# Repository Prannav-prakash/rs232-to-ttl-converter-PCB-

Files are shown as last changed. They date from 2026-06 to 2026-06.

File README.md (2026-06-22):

# RS232-to-ttl-converter-PCB
RS232 to TTL interface PCB for connecting an Inertial Labs INS-DU to a Cube Orange Plus flight controller at 921600 bps.

# Overview

This project implements a dedicated RS232-to-TTL interface board for communication between an Inertial Labs INS-DU navigation system and a Cube Orange Plus flight controller.

The board performs RS232 level shifting using the MAX3232E transceiver while also providing a power passthrough interface from an external BEC to the INS-DU. The design supports high-speed serial communication at up to 921600 baud and was developed using KiCad.

# Features
RS232 to TTL voltage level conversion using MAX3232
Compatible with Cube Orange Plus flight controller
Compatible with Inertial Labs INS-DU navigation system
Supports serial communication up to 921600 baud
External BEC power passthrough to INS-DU

# System Architecture

Cube Orange Plus UART (TTL)

↓

MAX3232E Level Shifter

↓

INS-DU RS232 Interface

Power for the INS-DU is supplied independently through an external BEC and routed through the PCB.

# Hardware Components
Integrated Circuits
MAX3232E RS232 Transceiver
Passive Components
Charge pump capacitors required by MAX3232
Power supply decoupling capacitor
Connectors
Cube Orange Plus Interface Connector
INS-DU Interface Connector
BEC Power Input Connector

# Repository Contents
KiCad Schematic Files

KiCad PCB Layout Files

Custom Symbols

Custom Footprints

3D Models

Documentation

Images
# PCB layout


# schematic 


# 3D view 


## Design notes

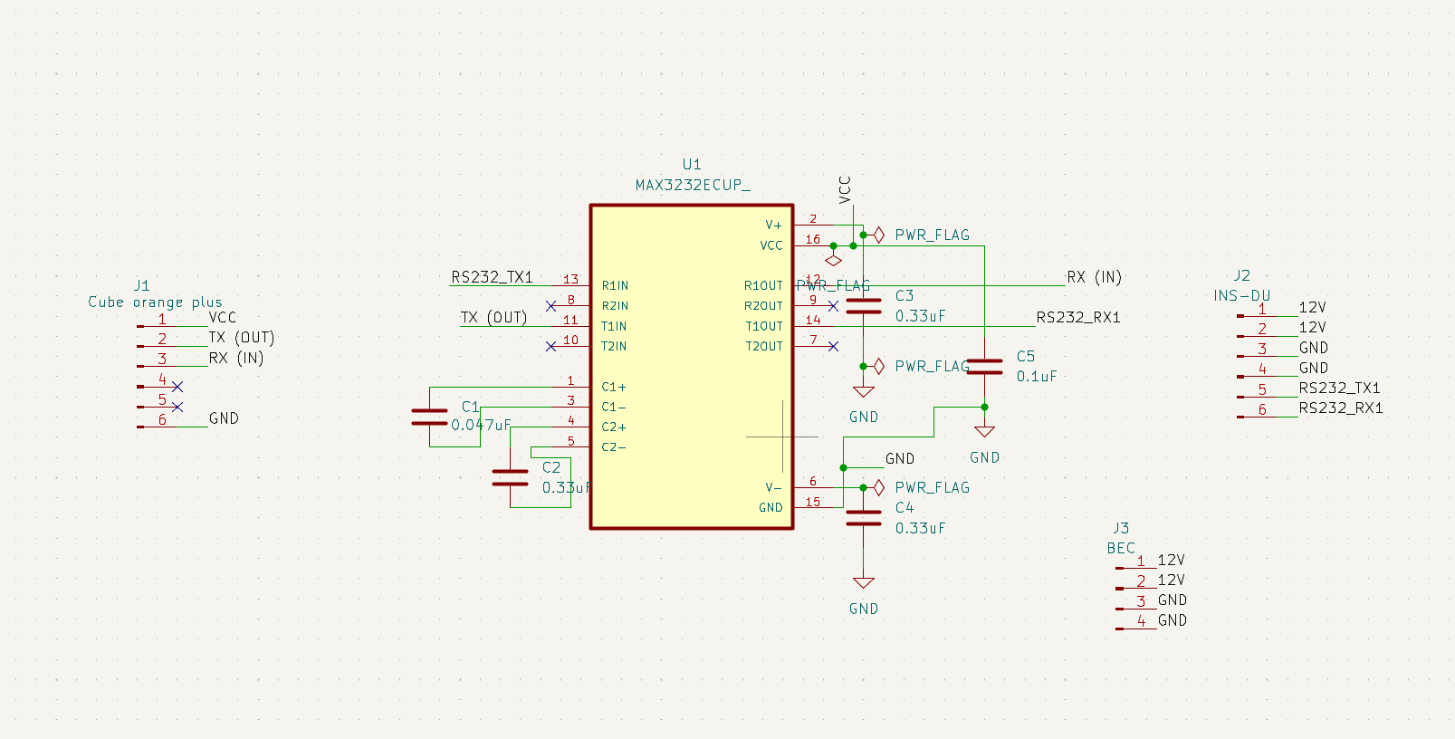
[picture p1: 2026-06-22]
schematic.png

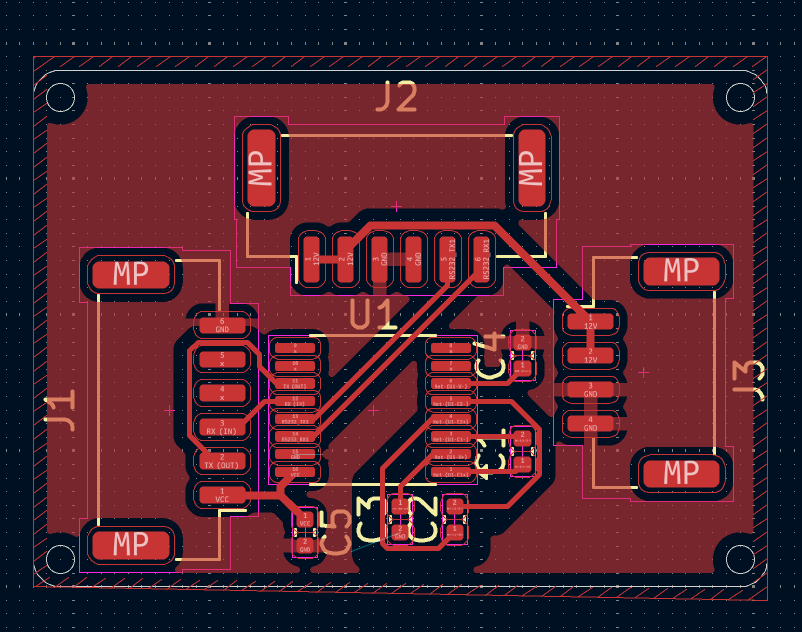
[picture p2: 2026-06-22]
PCB.png

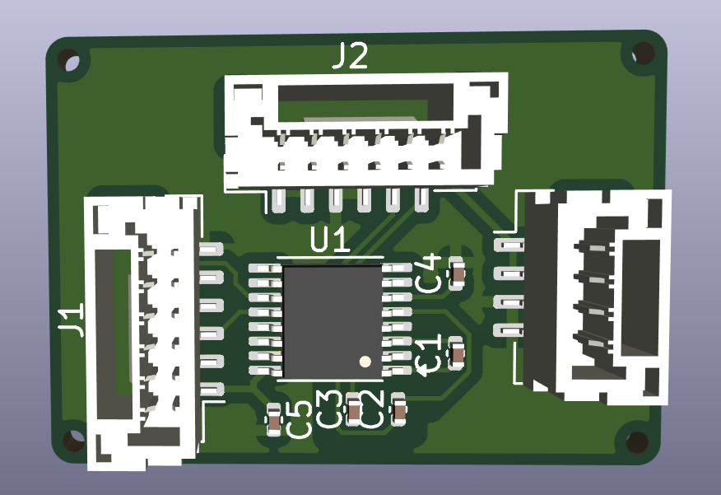
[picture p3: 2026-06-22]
3D view.png

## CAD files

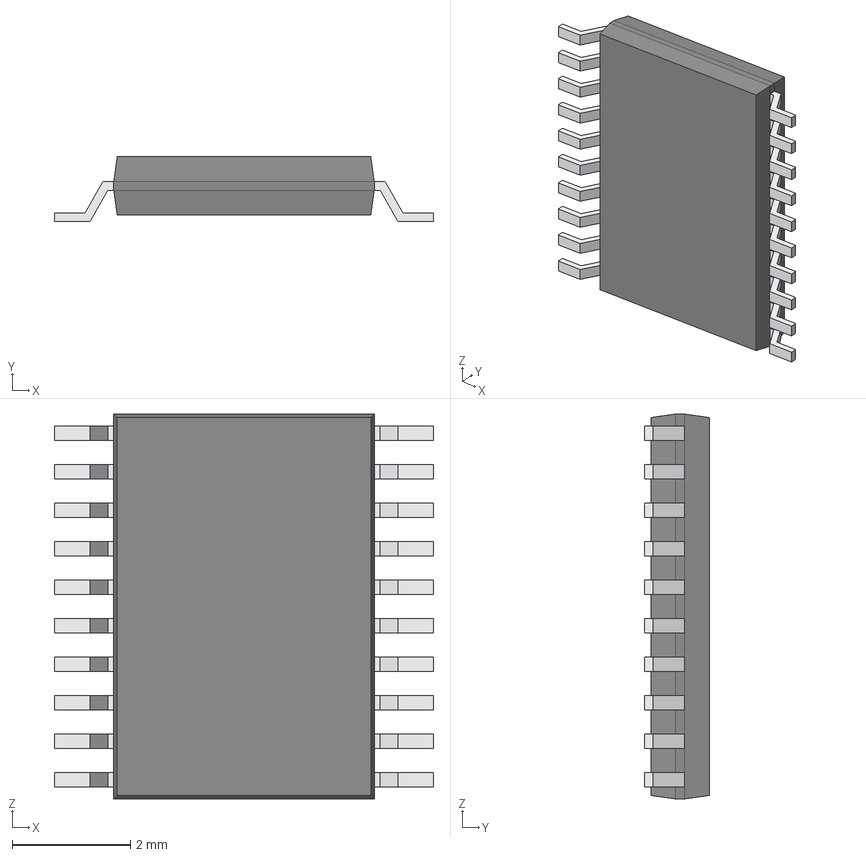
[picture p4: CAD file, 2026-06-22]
MAX3232ECUP_/MAX3232ECUP_.step
6.40 x 1.10 x 6.50 mm
Body001 (Mirror #1) x 10

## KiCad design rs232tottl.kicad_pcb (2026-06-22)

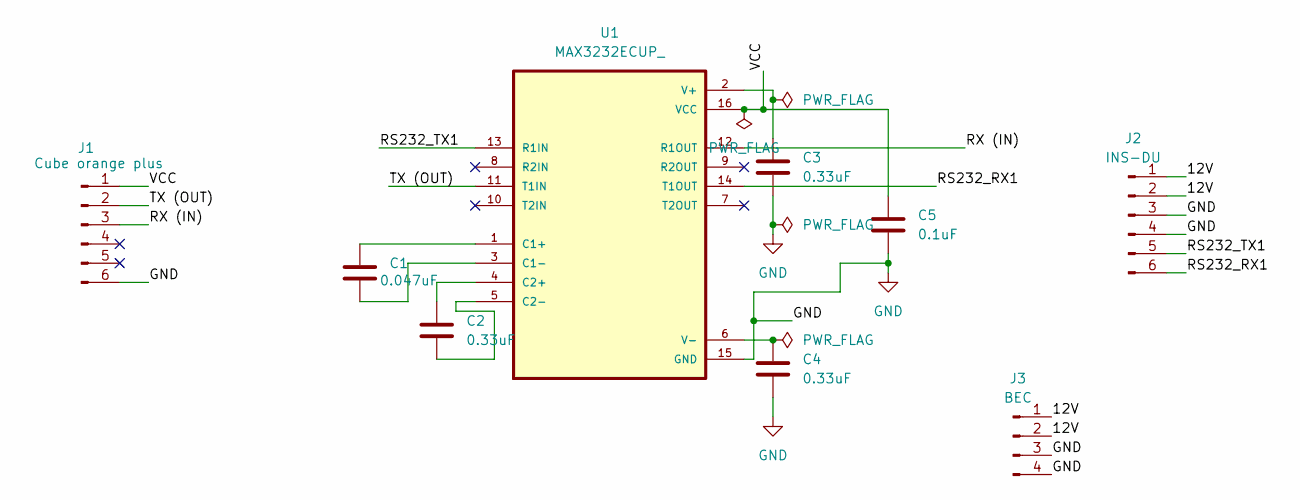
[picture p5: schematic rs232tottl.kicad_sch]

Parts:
C1: 0.047uF; C_0402_1005Metric
C2, C3, C4: 0.33uF; C_0402_1005Metric
C5: 0.1uF; C_0402_1005Metric
J1: Cube orange plus; JST_GH_BM06B-GHS-TBT_1x06-1MP_P1.25mm_Vertical
J2: INS-DU; JST_GH_BM06B-GHS-TBT_1x06-1MP_P1.25mm_Vertical
J3: BEC; JST_GH_BM04B-GHS-TBT_1x04-1MP_P1.25mm_Vertical
U1: MAX3232ECUP_; TSSOP-16_4.4x5mm_P0.65mm

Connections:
/12V: J2.1, J2.2, J3.1, J3.2
/RS232_RX1: J2.6, U1.14 (T1OUT)
/RS232_TX1: J2.5, U1.13 (R1IN)
/RX (IN): J1.3, U1.12 (R1OUT)
/TX (OUT): J1.2, U1.11 (T1IN)
/VCC: C5.1, J1.1, U1.16 (VCC)
GND: C3.2, C4.2, C5.2, J1.6, J2.3, J2.4, J3.3, J3.4, U1.15 (GND)
unnamed: C1.1, U1.1 (C1+)
unnamed: C1.2, U1.3 (C1-)
unnamed: C2.1, U1.4 (C2+)
unnamed: C2.2, U1.5 (C2-)
unnamed: C3.1, U1.2 (V+)
unnamed: C4.1, U1.6 (V-)

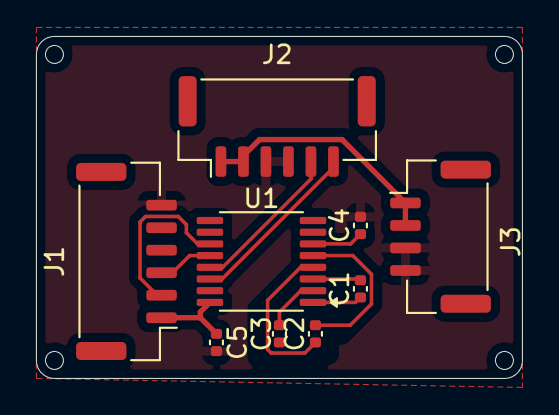
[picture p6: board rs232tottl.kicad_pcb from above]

Board: 2 copper layers, 27.0 x 19.0 mm, 9 parts (0 on the bottom side), 13 nets.

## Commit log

2026-06-22 KiCad project files
    [MAX3232ECUP_.step, rs232tottl.kicad_pcb, rs232tottl.kicad_sch]
2026-06-22 KiCad files
    [rs232tottl.kicad_pcb, rs232tottl.kicad_sch]
2026-06-22 Images of the board
2026-06-22 Enhance README with project details and images
    Expanded the README.md file to include an overview, features, system architecture, hardware components, repository contents, and images related to the RS232-to-TTL converter PCB.
